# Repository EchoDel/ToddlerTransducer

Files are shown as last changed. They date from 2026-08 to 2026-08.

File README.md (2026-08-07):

# ToddlerTransducer
Project for playing audio from a speaker using physical pucks. These use an RFID/NFC tag to identify which song to play.

# Functionality

1. Playback of audio when a puck is placed on top.
2. Playback of audio through a web app.
3. Uploading of new audio tracks through a web app.
4. Over the air updated from the github repo.

## What does the Playback Loop do

Check if tag is present
If there is no change then continue
If there wasn't before and is now load new song and start playing
If there was before and isn't now, fade out
If the tag has changed id then change song

# How does the OTA update work

The OTA update checks if there has been an update to the git repo, and if there has been then pull it, rebuild the package and relaunch the application.

This is built on the work done by Dhiraj Patra.
https://dhirajpatra.medium.com/ota-for-python-application-running-in-raspberry-pi-967e3e8d591d

## How does the web app work

The web app is built on flask and multithreaded with the other threads by constructing the app once the multithreading proxies have been initialized.

Flask App
https://www.geeksforgeeks.org/python/how-to-add-authentication-to-your-app-with-flask-login/
https://www.digitalocean.com/community/tutorials/how-to-make-a-web-application-using-flask-in-python-3
https://stackabuse.com/step-by-step-guide-to-file-upload-with-flask/

The raspberry pi will launch its own wifi hotspot when you press the button on the top.
https://www.raspberrypi.com/documentation/computers/configuration.html#enable-hotspot
https://askubuntu.com/questions/155791/how-do-i-sudo-a-command-in-a-script-without-being-asked-for-a-password/155827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

Select box for playing the next song.
https://select2.org/getting-started/installation

Additionally, you can back up the files from the TT by downloading a packing with all the songs and the metadata.
No upload has been created yet but this will need to load on top of the previous data.

# How the songs are played

Behind the scenes VLC is used to play the audio. This is controlled with the python vlc bindings. 
This package seems to be built in a C way instead of pythonic so its quite complicated to use.

VLC Python docs, https://www.olivieraubert.net/vlc/python-ctypes/doc/
Loop VLC, https://stackoverflow.com/questions/7214843/repeating-single-movie-using-python-bindings-for-vlc-what-is-a-psz-name

# Todo

- [x] Wiring Diagram
  - [ ] Add a filter for the noise, https://andybrown.me.uk/2015/07/24/usb-filtering/
- [ ] Finalise enclosure
- [x] Basic Software
  - [x] Seamless looping of puck
  - [x] Add a physical button for the looping and get light to toggle when switched in UI
- [x] OTA Update
  - [x] Build Pipeline
- [x] Playback without puck
- [x] Codeless adding of new files
- [x] Type hints and doc strings
- [x] Clean up GPIO after stopping
- [x] Error check and keep backups of the metadata
- [x] VLC to its own thread
- [ ] Add the ability to check if the songs inputs is valid / move to a different selection list

# Install

1. Set up a new raspberry pi
2. Install VLC
   * `sudo apt install vlc`
3. clone the git repo,
   * `git clone https://github.com/EchoDel/ToddlerTransducer.git`
4. Change to that folder
   * `cd ToddlerTransducer`
5. Copy the service 
   * `sudo cp ./install/ToddlerTransducer.service /etc/systemd/system/ToddlerTransducer.service`
6. Launch the service for the first time
   * `sudo systemctl start ToddlerTransducer.service`
   * Validate that it has started correctly
7. Setup the automated updates
   * `crontab -e`
   * `Add the following;  */5 * * * * /home/pi/ToddlerTransducer/install/ota_update.sh`

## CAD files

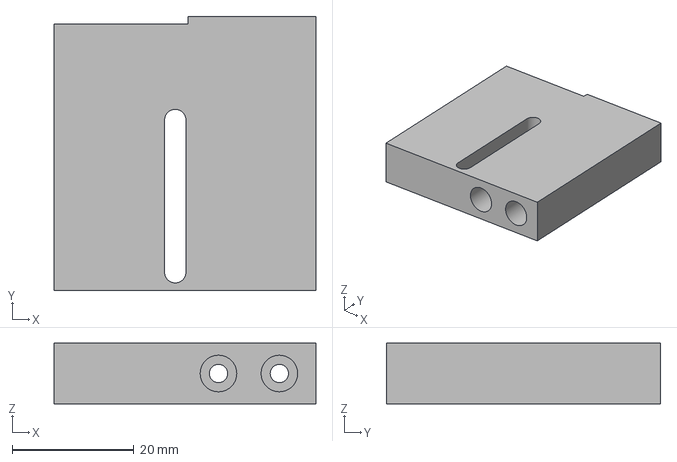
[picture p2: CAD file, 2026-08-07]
models/Box/Skeleton - RotaryEncoderMount.3mf
43.0 x 45.0 x 10.0 mm

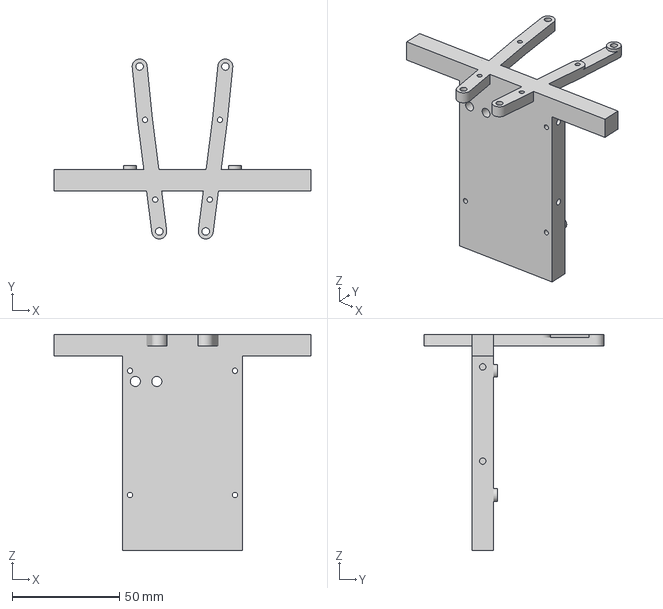
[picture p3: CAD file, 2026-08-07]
models/Box/Skeleton - Skeleton.3mf
120.0 x 84.0 x 101.0 mm

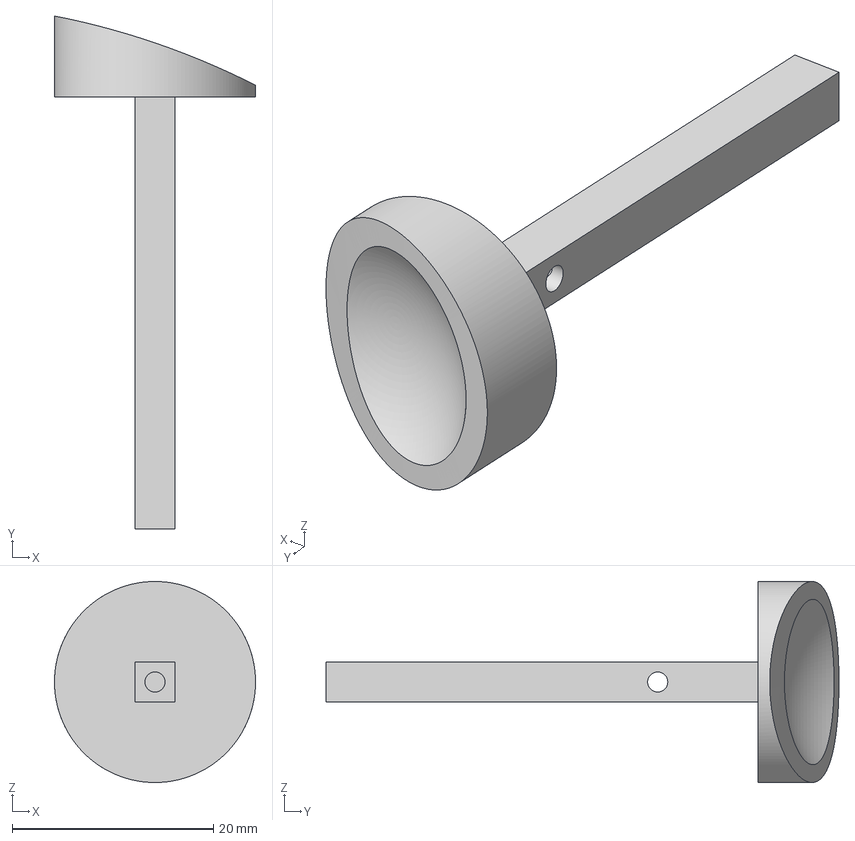
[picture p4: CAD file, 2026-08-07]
models/Box/BottomOutside - OnSwitch.3mf
20.0 x 51.0 x 20.0 mm

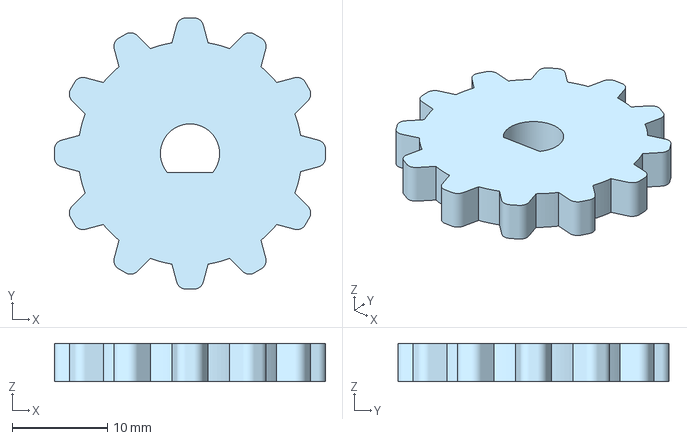
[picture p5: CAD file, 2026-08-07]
models/Box/RotaryEncoderGear - RotaryEncoderGear.3mf
28.4 x 28.4 x 4.00 mm

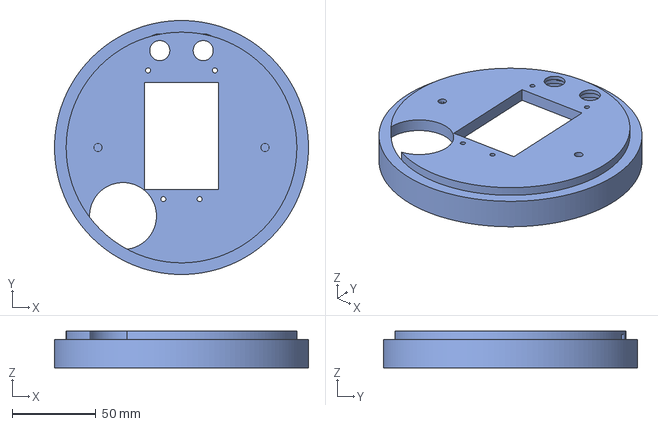
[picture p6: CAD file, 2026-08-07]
models/Box/TopPlate - BottomPlate.3mf
152.0 x 152.0 x 22.1 mm

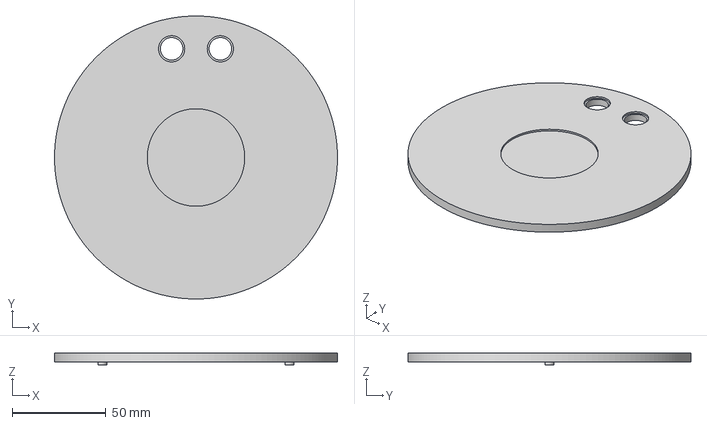
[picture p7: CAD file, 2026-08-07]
models/Box/TopPlate - TopPlate.3mf
151.0 x 151.0 x 6.60 mm

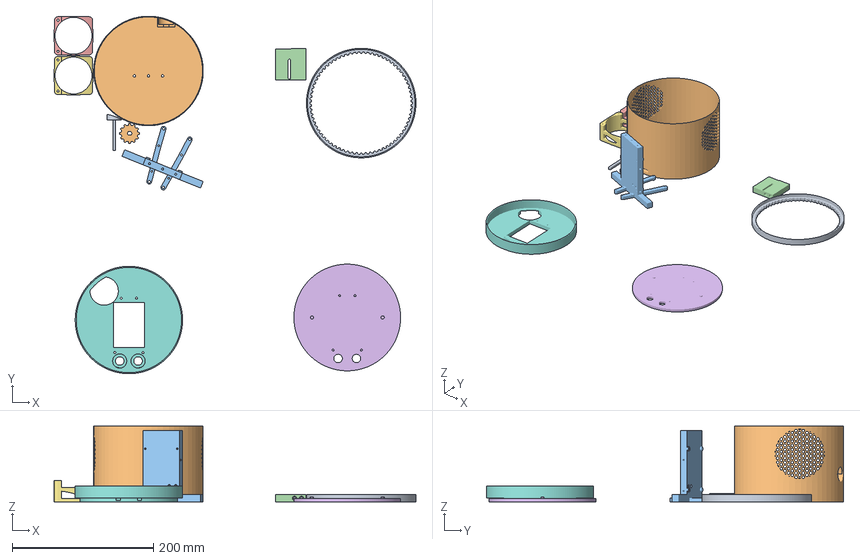
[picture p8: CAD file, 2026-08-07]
models/Box/ToddlerTransducerModel.3mf
512.3 x 505.9 x 107.0 mm
VolumeDisk
BottomOutside
Skeleton
RotaryEncoderMount
RightSpeaker x 2
TopPlate
BottomPlate
OnSwitch
RotaryEncoderGear

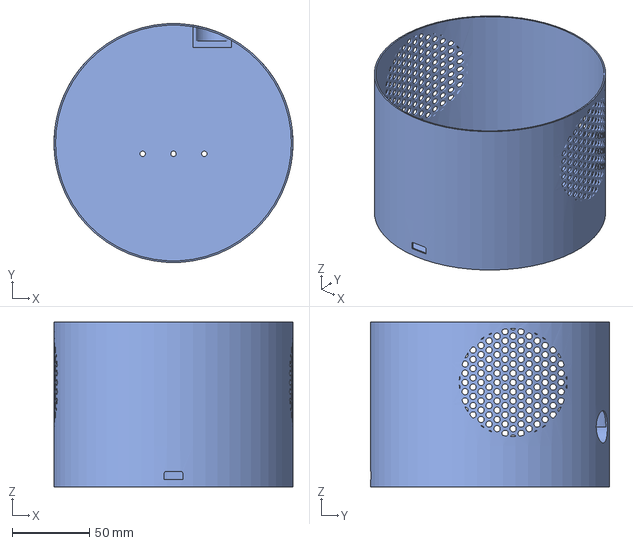
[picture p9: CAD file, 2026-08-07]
models/Box/BottomOutside - BottomOutside.3mf
155.0 x 154.8 x 107.0 mm

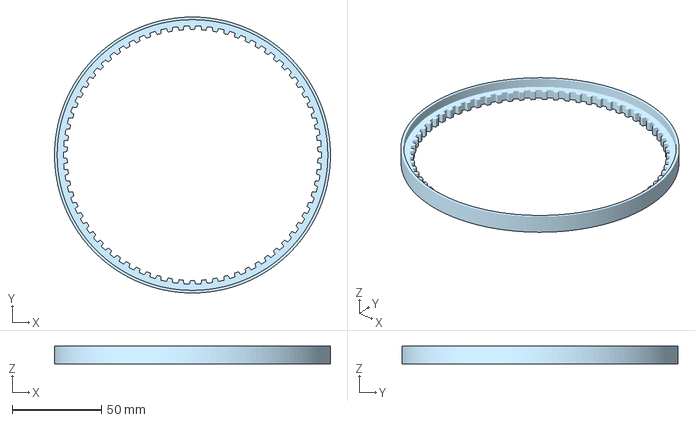
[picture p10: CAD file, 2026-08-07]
models/Box/TopPlate - VolumeDisk.3mf
155.0 x 155.0 x 10.00 mm

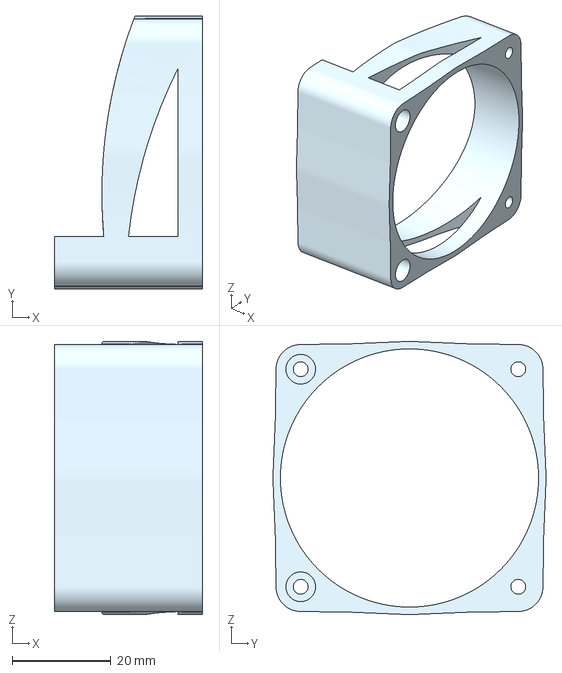
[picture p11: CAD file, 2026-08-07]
models/Box/Skeleton - RightSpeaker.3mf
30.0 x 55.2 x 55.2 mm

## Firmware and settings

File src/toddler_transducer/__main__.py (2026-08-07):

"""
Main

Contains the main function which setups up all the subprocess and controls the flow of data between them.
"""
import signal
import time
import sys
from multiprocessing import Process, Manager

import toddler_transducer.proxies.fake_rpi_setup
from toddler_transducer.rfid import threaded_get_rfid_id
from toddler_transducer.audio import VLCControlDict, launch_vlc_threaded, load_saved_volume, load_saved_puck_lockout
from toddler_transducer.gpio import gpio_update_loop
from toddler_transducer.puck_playback import puck_playback_loop
from toddler_transducer.web_ui.launch import launch_toddler_transducer_web_app


def main() -> None:
    """Entry point: set up subprocesses for RFID, GPIO, VLC, puck playback, and web UI."""

    def term_handler(signum: int, frame) -> None:
        """
        Handles the sigterm event so that the gpio can be cleaned up if its being used.
        Based on this blog;
         * https://chadrick-kwag.net/posts/python-interrupt-sigterm-sigkill-exception-handling-experiments/

        Args:
            signum: Signal number.
            frame: Current stack frame.
        """
        print("sig term handler")
        # https://stackoverflow.com/questions/56098431/runtimewarning-this-channel-is-already-in-use
        try:
            import RPi.GPIO
            RPi.GPIO.cleanup()
        except ImportError:
            pass
        sys.exit(0)

    signal.signal(signal.SIGTERM, term_handler)

    multithread_manager = Manager()
    rfid_tag_proxy = multithread_manager.Value('i', None)
    vlc_playback_manager: VLCControlDict = multithread_manager.dict(
        {'play_rfid_id': False,
        'play_track_name': False,
        'do_play': False,
        'do_stop': False,
        'do_pause': False,
        'toggle_looping': False,
        'seek_position': -1.0,
        'volume': load_saved_volume(),
        'puck_lockout': load_saved_puck_lockout(),

        # State outputs
        'playback_source': None,
        'is_playing': None,
        'is_looping': None,
        'current_playing_track_uuid': None,
        'track_length': None,
        'track_time_through': None,
        })

    wifi_manager: VLCControlDict = multithread_manager.dict(
        {'wifi_state': False,
         })

    # Start the rfid process
    rfid_process = Process(target=threaded_get_rfid_id, args=(rfid_tag_proxy,))
    rfid_process.start()

    # Start the button process
    button_process = Process(target=gpio_update_loop, args=(wifi_manager, vlc_playback_manager, ))
    button_process.start()

    # Start the vlc process
    vlc_process = Process(target=launch_vlc_threaded, args=(vlc_playback_manager, ))
    vlc_process.start()

    # Start the puck playback loop
    puck_playback_process = Process(target=puck_playback_loop, args=(rfid_tag_proxy, vlc_playback_manager))
    puck_playback_process.start()

    # Start the flask app
    flask_process = Process(target=launch_toddler_transducer_web_app, args=(rfid_tag_proxy, vlc_playback_manager))
    flask_process.start()
    while True:
        time.sleep(100000)  # Main loop has to keep running until all the process finish

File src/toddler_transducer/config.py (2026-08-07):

"""
Config

Module containing the config for the application
"""
from pathlib import Path

AUDIO_FILE_BASE_PATH = Path('./audio_files')
METADATA_FILE_PATH = AUDIO_FILE_BASE_PATH / 'metadata'
BACKUP_FILE_BASE_PATH = Path('./backups')
BACKUP_FILE_BASE_PATH.mkdir(parents=True, exist_ok=True)

VOLUME_FILE_PATH = Path('./persistent_settings.json')

# AI model backend selection — "hunyuan3d" or "instantmesh"
AI_MODEL_BACKEND = "hunyuan3d"

# GPIO pins
LOOPING_SENSE_PIN = 38
LOOPING_INDICATOR_PIN = 40

WIFI_SENSE_PIN = 36
WIFI_INDICATOR_PIN = 35

# Rotary encoder pins (BOARD numbering)
ENCODER_CLK_PIN = 5
ENCODER_DT_PIN = 7
ENCODER_VOLUME_NOTCH_PER_STEP = 2
ENCODER_VOLUME_INCREASE_PER_STEP = 1

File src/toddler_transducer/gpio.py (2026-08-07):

"""
GPIO

General module to handle the GPIO requirements
"""
import time
from multiprocessing.managers import DictProxy

from RPi import GPIO

from toddler_transducer.audio import save_volume
from toddler_transducer.config import LOOPING_SENSE_PIN, LOOPING_INDICATOR_PIN, WIFI_SENSE_PIN, WIFI_INDICATOR_PIN
from toddler_transducer.config import (ENCODER_CLK_PIN, ENCODER_DT_PIN,
                                       ENCODER_VOLUME_NOTCH_PER_STEP, ENCODER_VOLUME_INCREASE_PER_STEP)

GPIO.setmode(GPIO.BOARD)

class LEDSwitch:
    """
    Class to handle a momentary with an LED status indicator
    """
    def __init__(self, sense_pin: int, indicator_pin: int):
        self.sense_pin = sense_pin
        self.indicator_pin = indicator_pin
        GPIO.setup(self.sense_pin, GPIO.IN, pull_up_down=GPIO.PUD_UP)
        GPIO.setup(self.indicator_pin, GPIO.OUT)
        self.indicator_status = False
        self.was_high = False

    def update_led(self):
        """
        Sets the LED output to be that of the indicator status.
        """
        GPIO.output(self.indicator_pin, self.indicator_status)

    def toggle(self):
        """
        Toggles the state.
        """
        self.indicator_status = not self.indicator_status
        self.update_led()

    def switch_on(self):
        """
        Turns the switch on.
        """
        self.indicator_status = True
        self.update_led()

    def switch_off(self):
        """
        Turns the switch of.
        """
        self.indicator_status = False
        self.update_led()

    def get_input(self):
        """
        Gets the input from the momentary switch.
        """
        return GPIO.input(self.sense_pin)

    def update(self):
        """
        Updates the status and output. On the falling edge
        """
        if self.get_input() == GPIO.LOW:
            if self.was_high:
                self.toggle()
            self.was_high = False
        else:
            self.was_high = True


class RotaryEncoderVolume:
    """
    Reads a rotary encoder to control volume with configurable gearing.

    Args:
        clk_pin (int): BOARD pin number for the CLK output.
        dt_pin (int): BOARD pin number for the DT output.
        steps_per_notch (int): How many detent steps equal one volume increment.
    """
    def __init__(self, clk_pin: int, dt_pin: int, notch_per_step: int, volume_per_step: int):
        self.clk_pin = clk_pin
        self.dt_pin = dt_pin
        self.notch_per_step = notch_per_step
        self.volume_per_step = volume_per_step
        GPIO.setup(self.clk_pin, GPIO.IN, pull_up_down=GPIO.PUD_UP)
        GPIO.setup(self.dt_pin, GPIO.IN, pull_up_down=GPIO.PUD_UP)
        self.last_clk = GPIO.input(self.clk_pin)
        self.counter = 0

    def update(self, vlc_playback_manager: dict):
        """
        Reads the encoder state and adjusts volume when the step threshold is reached.
        """
        current_clk = GPIO.input(self.clk_pin)
        if current_clk != self.last_clk:
            dt_state = GPIO.input(self.dt_pin)
            if dt_state != current_clk:
                self.counter += 1
            else:
                self.counter -= 1

            if self.counter >= self.notch_per_step:
                self.counter = 0
                current_vol = vlc_playback_manager.get('volume', 50)
                new_vol = max(0, min(100, current_vol + self.volume_per_step))
                vlc_playback_manager['volume'] = new_vol
                save_volume(new_vol)
            elif self.counter <= -self.notch_per_step:
                self.counter = 0
                current_vol = vlc_playback_manager.get('volume', 50)
                new_vol = max(0, min(100, current_vol - self.volume_per_step))
                vlc_playback_manager['volume'] = new_vol
                save_volume(new_vol)

        self.last_clk = current_clk
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

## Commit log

2025-09-20 Added the first pass of the kicard files
    [ToddlerTransducer.kicad_pcb, ToddlerTransducer.kicad_sch]
2025-09-26 Corrected the output for the pi
    [audio.py]
2025-09-29 Moved the flask app, rfid, and puck playback into multithreaded processes to avoid lockup of the gpio (#5)
    * Made the rfid get multithreaded to try to get both the flask app and puck playback working at once
    * Used the right method for putting data in the queue
    * Used the right method for finding data in the queue
    * Moved to list instead of deque since deque isn't supported by multithreading
    * Moved to multithreading list instead of a normal list since this isn't supported by multithreading
    * Corrected the RPi import
    * Moved to a value proxy
    * Used the value proxy properly
    * Made sure the main python script exists so that the value can be passed and the RFID get runs every 2 seconds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
    [__main__.py, audio.py, puck_playback.py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]
2025-09-30 Feature/multithreaded vlc (#7)
    * Moved VLC into its own thread so one instance can be controlled by the webui and the pucks
    * Tidied up the last couple of bits
2025-10-02 Added a pair of buttons 1 to control looping, 1 to control the wifi
    * Added a module to handle switches
    * Made the gpio run in the main loop
    * Corrected the scripts
    * Corrected the config import
    * Corrected the call
    * Corrected the call
    [__main__.py, config.py, gpio.py]
2025-10-12 Reworked the imports to work with minimum features when not on a rpi. (#9)
    * Added the first pass of the fake r pi gpio
    * Moved the proxies into their own packages
    * lint issues
    * Moved to checking if the machine is aarch instead of the os name
    * Added some missing files from the branch
    [__main__.py, audio.py, audio_file_manager.py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]
2025-10-13 Got the download of the backup working (#10)
    * Got the download of the backup working
    * Added the backups to the gitignore
    * Added the backups to the gitignore
    * Linting issues
    [__main__.py, audio.py, audio_file_manager.py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]
2025-10-15 Feature/looping fix (#11)
    * Removed the fake rpi package to avoid the random switching of the looping
    * Corrected the looping style
    * Added the missing package
    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
    [fake_raspberry_pi.py, gpio.py]
2026-06-21 Feature/fully webplayer UI (#15)
    * Reduced the audio level
    * Added all the code needed to have a full player in the webpage
    * Renamed the sample audio files to avoid overwriting
2026-06-22 Updated the webplayer to have a progress bar and simpler ui (#16)
    * Expanded the webpage to have a full player (#14)
    * Feature/fully webplayer UI (#15)
    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
    [__main__.py, audio.py]
2026-06-23 Saved the volume between reboots (#19)
    [__main__.py, audio.py, config.py]
2026-06-27 Added the delete button to the UI (#23)
2026-06-28 Added a reboot button to the UI (#25)
2026-07-08 Corrected the volume dial (#28)
    * Corrected the pins for the rotary encoder
    * Added a volume change per step
    [config.py, gpio.py]
2026-07-08 Added the ability to create a puck from a web based ui (#29)
    * Added the basic puck creation webpage
    * Added a basic AI mesh creator to the webpage
    * Added a fillet to the puck
    * Added doc strings
    * Rewrote the AI pipeline to be a few functions that do one function
    * Moved the placing of the AI gen mesh after creation of it so that it can be edited with the UI
    * Added hunyuan3d as a model generation option
    * Made the STL import functional
    * Added a rotation for all models on all axis
    * Moved the puck creation package to their own group to avoid overloading the PI.
    * Added a line on how to install VLC for Raspberry Pi
    [config.py]
2026-07-08 Corrected the rotary encoder logic (#30)
    [config.py, gpio.py]
2026-07-08 Feature/code cleanup (#31)
    * Doc strings and type hints
    * Corrected the tests
    [__main__.py, audio.py, audio_file_manager.py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]
2026-07-15 Added in the first version of the container (#33)
    [BottomOutside - BottomOutside.3mf, BottomOutside - OnSwitch.3mf, RotaryEncoderGear - RotaryEncoderGear.3mf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]
2026-07-15 Corrected the playback of the puck when not looping (#34)
    [puck_playback.py]
2026-09-01 Release 1.0.2 (#40)
    * Corrected the braindead fix to the latest backup retrieval logic
    [audio_file_manager.py]
